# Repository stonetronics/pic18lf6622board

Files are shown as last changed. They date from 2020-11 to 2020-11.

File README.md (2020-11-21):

# pic18lf6622board

A Arduino-like Microcontroller board with a PIC18LF6622 microcontroller

#### Features: #####

- PIC18LF6622 Microcontroller
 - PICKit header
 - 12MHz Crystal
- FT230XQ USB/Serial controller
 - Micro-USB connector
 - RX/TX disconnectable
- 5V and 3V3 Regulator
 - AMS1117: 1A
 - VDD and AVDD connectable to 5V, 3V3 and VUSB
- All useful pins on the controller are broken out on pinheaders
- 2 Layer Board
- drawn in KiCad
 
The Board is built to be programmed with a PICKit, altough one could also build a serial bootloader.

### Uart Driver ###
There is a MPLAB X Project UartTest.X that contains a test for a library that lets you use the uart. The driver is interrupt-driven and uses circular buffers to store incoming and outgoing data while not blocking the main program flow. This project can be used as template with integrated uart support + circular buffer middleware.

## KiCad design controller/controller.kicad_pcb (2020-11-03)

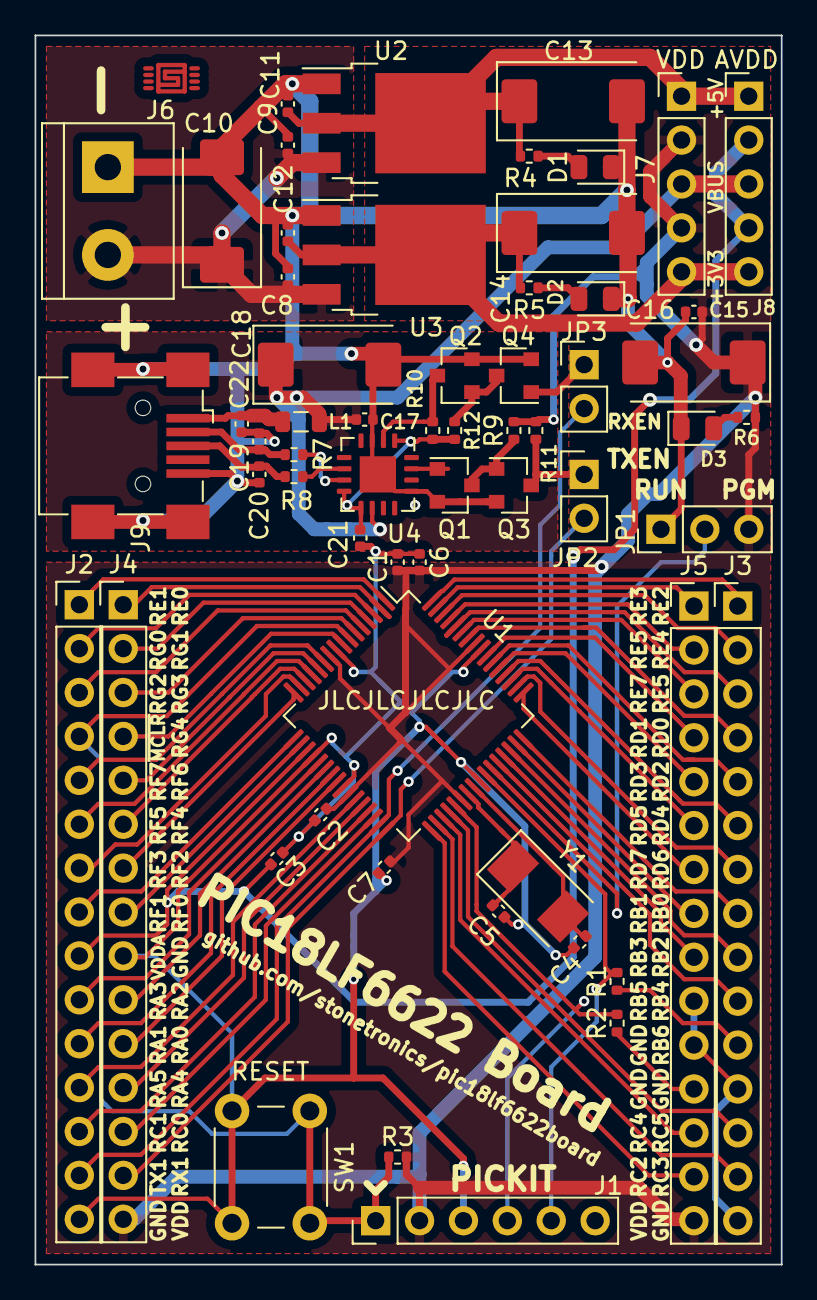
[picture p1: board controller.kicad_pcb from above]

Board: 2 copper layers, 43.2 x 71.1 mm, 60 parts (0 on the bottom side), 78 nets.

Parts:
C1, C2, C3, C6, C7, C8, C9, C11, C12, C15, C17, C21: 100n; C_0402_1005Metric
C4, C5: 22p; C_0402_1005Metric
C10, C13, C14, C16, C18: 150uF; CP_EIA-7343-31_Kemet-D
C19, C20: 47p; C_0402_1005Metric
C22: 10n; C_0402_1005Metric
D1, D2, D3: LED; LED_0805_2012Metric
J1: PICKIT; PinHeader_1x06_P2.54mm_Vertical
J2: IO_A; PinHeader_1x15_P2.54mm_Vertical
J3: IO_C; PinHeader_1x15_P2.54mm_Vertical
J4: IO_B; PinHeader_1x15_P2.54mm_Vertical
J5: IO_D; PinHeader_1x15_P2.54mm_Vertical
J6: POWER; TerminalBlock_bornier-2_P5.08mm
J7: VDD; PinHeader_1x05_P2.54mm_Vertical
J8: AVDD; PinHeader_1x05_P2.54mm_Vertical
J9: USB_B_Micro; USB_Mini-B_Wuerth_65100516121_Horizontal
JP1: PGM/RUN; PinHeader_1x03_P2.54mm_Vertical
JP2: TX; PinHeader_1x02_P2.54mm_Vertical
JP3: RX; PinHeader_1x02_P2.54mm_Vertical
L1: 600Ohm 100MHz; L_0805_2012Metric
Q1, Q2, Q3, Q4: BSS138; SOT-23
R1, R2: 100R; R_0402_1005Metric
R3: 10k; R_0402_1005Metric
R4, R6: 270R; R_0402_1005Metric
R5: 120R; R_0402_1005Metric
R7, R8: 27R; R_0402_1005Metric
R9, R10, R11, R12: 4k7; R_0402_1005Metric
SW1: Reset; SW_PUSH_6mm_H5mm
U1: PIC18LF6622-IPT; TQFP-64_10x10mm_P0.5mm
U2: AMS1117-5.0; TO-252-3_TabPin2
U3: AMS1117CD-3.3; TO-252-3_TabPin2
U4: FT230XQ; QFN-16-1EP_4x4mm_P0.65mm_EP2.1x2.1mm
Y1: 12 MHz; Crystal_SMD_Abracon_ABM3-2Pin_5.0x3.2mm

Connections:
+3V3: C12.2, C14.1, J7.5, J8.5, R5.1, U3.2
+5V: C11.2, C13.1, J7.1, J8.1, R4.1, U2.2
/PGC: J1.5, R1.2, U1.42
/PGD: J1.4, R2.2, U1.37
/PGM: JP1.2, U1.43
/RA0: J4.11, U1.24
/RA1: J2.11, U1.23
/RA2: J4.10, U1.22
/RA3: J2.10, U1.21
/RA4: J4.12, U1.28
/RA5: J2.12, U1.27
/RB0: J3.8, U1.48
/RB1: J5.8, U1.47
/RB2: J3.9, U1.46
/RB3: J5.9, U1.45
/RB4: J3.10, U1.44
/RC0: J4.13, U1.30
/RC1: J2.13, U1.29
/RC2: J5.14, U1.33
/RC3: J3.14, U1.34
/RC4: J5.13, U1.35
/RC5: J3.13, U1.36
/RD0: J3.4, U1.58
/RD1: J5.4, U1.55
/RD2: J3.5, U1.54
/RD3: J5.5, U1.53
/RD4: J3.6, U1.52
/RD5: J5.6, U1.51
/RD6: J3.7, U1.50
/RD7: J5.7, U1.49
/RE0: J4.1, U1.2
/RE1: J2.1, U1.1
/RE2: J3.1, U1.64
/RE3: J5.1, U1.63
/RE4: J3.2, U1.62
/RE5: J5.2, U1.61
/RE6: J3.3, U1.60
/RE7: J5.3, U1.59
/RF0: J4.8, U1.18
/RF1: J2.8, U1.17
/RF2: J4.7, U1.16
/RF3: J2.7, U1.15
/RF4: J4.6, U1.14
/RF5: J2.6, U1.13
/RF6: J4.5, U1.12
/RF7: J2.5, U1.11
/RG0: J2.2, U1.3
/RG1: J4.2, U1.4
/RG2: J2.3, U1.5
/RG3: J4.3, U1.6
/RG4: J4.4, U1.8
/~MCLR~: J1.1, J2.4, R3.1, SW1.1, U1.7
GND: C1.1, C2.1, C3.1, C4.1, C5.1, C6.1, C7.1, C8.1, C9.1, C10.2, C11.1, C12.1, C13.2, C14.2, C15.1, C16.2, C17.1, C18.2, C19.1, C20.1, C21.1, C22.1, D1.1, D2.1, D3.1, J1.3, J2.15, J3.12, J3.15, J4.9, J5.10, J5.11, J6.1, J9.5, J9.6, JP1.1, Q1.2, Q2.2, Q3.2, Q4.2, SW1.2, U1.9, U1.20, U1.25, U1.41, U1.56, U2.1, U3.1, U4.3, U4.13, U4.17
unnamed: C4.2, U1.40, Y1.2
unnamed: C5.2, U1.39, Y1.1
unnamed: C8.2, C9.2, C10.1, J6.2, U2.3, U3.3
unnamed: C19.2, J9.2, R7.2
unnamed: C20.2, J9.3, R8.1
unnamed: C21.2, R10.2, R12.2, U4.1, U4.8, U4.9
unnamed: C22.2, J9.1, L1.2
unnamed: D1.2, R4.2
unnamed: D2.2, R5.2
unnamed: D3.2, R6.2
unnamed: J3.11, R1.1
unnamed: J5.12, R2.1
unnamed: JP2.1, Q3.3, R11.1
unnamed: JP3.1, Q4.1
unnamed: Q1.1, U4.15
unnamed: Q1.3, Q3.1, R9.1
unnamed: Q2.1, Q4.3, R12.1
unnamed: Q2.3, R10.1, U4.2
unnamed: R7.1, U4.7
unnamed: R8.2, U4.6
RX1: J4.14, JP2.2, U1.32
TX1: J2.14, JP3.2, U1.31
VBUS: C17.2, C18.1, J7.3, J8.3, L1.1, U4.10
VDD: C1.2, C2.2, C6.2, C7.2, C15.2, C16.1, J1.2, J4.15, J5.15, J7.2, J7.4, JP1.3, R3.2, R6.1, R9.2, R11.2, U1.10, U1.26, U1.38, U1.57
VDDA: C3.2, J2.9, J8.2, J8.4, U1.19

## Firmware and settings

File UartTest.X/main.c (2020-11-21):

/*
 * File:   main.c
 * Author: stone
 *
 * Created on November 7, 2020, 6:30 PM
 */


#include "config.h"
#include <xc.h>
#include <stdint.h>

#include "uart.h"
#include "circularBuffer.h"

void main(void) {
    uint8_t rxChar;
    
    uart_init(19200);
    
    //IO Test
    //TRISE |= (1<<0); //RE0 input
    TRISE &= ~(1<<1); //RE1 output
    //PORTE |= (1<<1); //set RE1 HIGH
    PORTE &= ~(1<<1); //set RE1 LOW
    
    //enable interrupts
    INTCONbits.PEIE = 1;
    INTCONbits.GIE = 1;

    while(1)
    {
        if(uart_testAndGetc(&rxChar))
        {
            uart_print("got character: '");
            uart_putc(rxChar);
            uart_println("' I hope you like this one:");
            uart_printUint8(1);
            uart_println("");
            uart_printUint8(12);
            uart_println("");
            uart_printUint8(123);
            uart_println("");
            uart_printByteBinary(0x55);
            uart_println("");
            uart_printByteHex(255);
            uart_println("");
            uart_printInt32(-16);
            uart_println("");
            uart_printInt32(23232323);
            uart_println("");
            uart_printFloat(12.777, 2);
            uart_println("");
            uart_printFloat(-7.2, 5);
            uart_println("");
        }
        
       /*
        * 
        
        if (PORTE &(1<<0)) //RE0 high
        {
            LATE |= (1<<1); //RE1 high
        } else {
            LATE &= ~(1<<1); //RE1 low
        }
         * 
         * */
        
    }
    
    return;
}

void __interrupt () theInterrupt(void)
{
    if(PIE1bits.RC1IE && PIR1bits.RC1IF)
    {
        uart_rxInterrupt();
    }
    if(PIE1bits.TX1IE && PIR1bits.TX1IF)
    {
        uart_txInterrupt();
    }
}

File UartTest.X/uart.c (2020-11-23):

#include "uart.h"
#include "circularBuffer.h"

#define BUFFERSIZE_RX   16
#define BUFFERSIZE_TX   64

volatile uint8_t rxBufferMemory[BUFFERSIZE_RX];
volatile uint8_t txBufferMemory[BUFFERSIZE_TX];

volatile CircularBuffer rxBuffer;
volatile CircularBuffer txBuffer;

volatile uint8_t sending;


void uart_init(const uint32_t baudrate)
{
  //init buffers
    circularBuffer_init(&rxBuffer, rxBufferMemory, BUFFERSIZE_RX);
    circularBuffer_init(&txBuffer, txBufferMemory, BUFFERSIZE_TX);
    
    sending = 0;
    
    int16_t a = ( F_OSC / (16 * baudrate) ) - 1;

    if (a < 0)
      a = 0;

    if (a > 255) //low speed
    {
      a = ( F_OSC / (64 * baudrate) ) - 1;
      if (a > 255)
        a = 255;
      SPBRG1 = a;
      TXSTA1 = (1<<5);  // transmit enabled, low speed mode
    }

    else //high speed
    {
      SPBRG1 = a;
      TXSTA1 = (1<<5) | (1<<2);  // transmit enabled, high speed mode
    }

    RCSTA1 = (1<<7) | (1<<4);  // serial port enabled, continues receive enabled

    //enable receive interrupt
    PIE1bits.RC1IE = 1;
 
}
 
uint8_t uart_dataReady()
{
  if(circularBuffer_isEmpty(&rxBuffer))
    return 0;
  return 1;
}

uint8_t uart_testAndGetc(char* c)
{
    return circularBuffer_read(&rxBuffer, c);
}
 
uint8_t readReg()
{
    while (RCIF == 0);  //wait until there is data in the TXREG
    if (OERR1)
    {  // clear eventual overrun error
        CREN1 = 0;
        CREN1 = 1;
    }
    return RCREG1;  //read the received data
}
 
void uart_putc(const char a)
{
    
    if (!sending)
    {
        while (TRMT1 == 0); //wait until there is no transmission going on
        
        TXREG1 = a;     //start next transmission
        sending = 1;
        //enable tx interrupt
        PIE1bits.TX1IE = 1;
        
    } else {
        while (circularBuffer_isFull(&txBuffer)); //wait until tx buffer can take new data
        circularBuffer_write(&txBuffer, a);
    }
    
}

void uart_print(const char* a)
{
    uint8_t i = 0;
    while (a[i] != '\0')
        uart_putc(a[i++]);
}

void uart_newline()
{
    uart_putc('\n');
    uart_putc('\r');
}

void uart_println(const char* a)
{
    uart_print(a);
    uart_newline();
}

void uart_printUint8(uint8_t a)
{
    uint8_t divisor = 1;
    if (a == 0)
    {
        uart_putc('0');
    } else {   
        while (divisor < a)
        {
            divisor *= 10;
            if (divisor == 100)
                break;
        }

        if ((a%(divisor*10))/(divisor) == 0)
            divisor /= 10; //skip first zero if necessary

        while (divisor >= 1)
        {
            uart_putc('0' + (a%(divisor*10))/(divisor));
            divisor /= 10;
        }
    }
}

void uart_printByteBinary(uint8_t a)
{
    uint8_t i;
    
    uart_putc('0');
    uart_putc('b');
    
    for (i = 0; i < 8; i++)
    {
        if (a & (1 << (7-i)))
            uart_putc('1');
        else
            uart_putc('0');
    }
}

void uart_printByteHex(uint8_t a)
{
    uart_putc('0');
    uart_putc('x');
    if (((a&0xF0)>>4) < 10)
        uart_putc('0' + ((a&0xF0)>>4) );
    else
        uart_putc('A' - 10 + ((a&0xF0)>>4));
    if ((a&0x0F) < 10)
        uart_putc('0' + a&0x0F);
    else
        uart_putc('A' - 10 + (a&0x0F));
}

void uart_printInt32(int32_t a)
{
    int32_t modulor = 1;
    
    if (a == 0)
    {
        uart_putc('0');
    } else {
        if (a < 0)
        {
            uart_putc('-');
            a *= -1;
        }

        while (modulor < a)
        {
            modulor *= 10;
            if (modulor == 1000000000)
                break;
        }

        while (modulor > 1)
        {
            uart_putc('0' + (a%modulor)/(modulor/10));
            modulor /= 10;
        }
    }
    
}

void uart_printFloat(float a, uint8_t digitsAfterComma)
{
    uint8_t d;
    uint8_t i =0;
    
    uart_printInt32((int32_t)a);
    uart_putc('.');
    
    a = a - (int32_t) a;
    if (a < 0.0)
        a *= -1;
    
    while (i++ < digitsAfterComma)
    {
        a *= 10.0;
        d = (uint8_t) a;
        uart_putc('0'+d%10);
    }
}

//transmission complete interrupt
void uart_txInterrupt(void)
{
    
    uint8_t txChar;
    if (circularBuffer_isEmpty(&txBuffer))
    {
        sending = 0;
        //enable tx interrupt
        PIE1bits.TX1IE = 0;
    } else {
        circularBuffer_read(&txBuffer, &txChar);
        uart_putc(txChar);
    }
    
    return;
}

//reception interrupt
void uart_rxInterrupt(void)
{
    circularBuffer_write(&rxBuffer, RCREG1);
    
    return;
}

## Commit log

2020-11-21 add uart driver
    [controller.kicad_pcb, controller.sch, controllerPower.sch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]
2020-11-23 fix bug with displaying '0', disable watchdog in config setup
    [uart.c]
